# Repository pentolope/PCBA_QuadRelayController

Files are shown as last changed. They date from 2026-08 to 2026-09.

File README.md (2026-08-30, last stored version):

# Four-Channel Relay Controller

Four-channel relay controller run by a small MCU on 5 V logic, switching external loads through screw terminals with the switched side kept apart from logic.

This repository seeds the design of a four-channel relay controller operated by a small MCU, with 5 V logic power and each relay switching an external load through screw terminals. The brief fixes the functional block list — input protection, transistor/MOSFET relay drivers, flyback suppression, status indication, and a programming interface — and imposes one layout-level constraint: the switched side must be physically separated from the logic side, with conservative clearances appropriate to a voltage rating the design agent selects and documents. Beyond those items nothing is pinned down. No relay, MCU, driver device, terminal block, protection part, programming standard, board outline, or stackup is named. The switched-side voltage rating is explicitly delegated — it is one "you select and document" — while the switched-side current rating and whether the load is AC or DC are never mentioned at all, and so are open by silence. Most of the architecture therefore belongs to the design agent; the brief supplies the block list and the separation constraint, not the implementation.

> **This board has not been designed.** There is no schematic, no layout and no
> part selection here — only the brief, a reading of the brief, and the
> scaffolding a design run needs. That is the intended state of this repository,
> not a gap in it.

## What the brief fixes, and what it leaves open

The brief pins down 13 requirements and deliberately leaves
20 decisions to whoever designs the board. The `Source` column says
which is which: `brief` is quoted from [BRIEF.md](BRIEF.md), `metadata` comes
from the benchmark catalogue, and `open` means the brief does not fix it.

| Aspect | Value | Source |
|---|---|---|
| Channel count | Four relay channels | brief |
| Controller | A small MCU; no family, part, package or core named | brief |
| Logic supply | 5 V | brief |
| Load connection | Each relay switches an external load through screw terminals | brief |
| Relay driver stage | Transistor/MOSFET relay drivers required; device and topology unspecified | brief |
| Flyback suppression | Required; suppression method not specified | brief |
| Input protection | Required; protected nodes and scheme not specified | brief |
| Status indication and programming interface | Both required; indication form, programming standard and the physical form of the interface all unspecified | brief |
| High/low voltage partition | Switched side physically separated from logic side | brief |
| Switched-side voltage rating, current rating and clearance values | Not fixed by the brief; the design agent selects and documents the voltage rating and chooses conservative clearances appropriate to it. The current rating and whether the load is AC or DC are not mentioned at all and are equally the agent's to decide. | open |
| Relay selection (coil voltage, contact form and rating, mounting style) | Design agent's choice; the brief names no relay | open |
| Board outline, size, mounting and terminal pitch | Design agent's choice; the brief states no mechanical envelope | open |
| Likely layer count | 2 | metadata |
| Category / difficulty / brief detail | industrial-control; difficulty 2; detail 2 | metadata |

The full split, with the verbatim brief text substantiating every fixed
requirement, is in [board/requirements.md](board/requirements.md) and
machine-readably in [board/requirements.json](board/requirements.json).

**Missing details are design freedom, not permission to fabricate unstated user
requirements.** A choice the brief left open is recorded as a decision, with its
reasoning — never promoted into a requirement.

## Benchmark position

| | |
|---|---|
| Benchmark id | 3 of 32 |
| Category | industrial-control |
| Difficulty | 2 / 5 |
| Brief detail | 2 / 5 |
| Likely layer count | 2 |
| Primary stressors | high/low voltage partition, relay flyback, creepage/clearance, terminal placement |

At difficulty 2 and detail 2 in the industrial-control category, this board tests whether an agent can execute a conventionally-shaped circuit while getting the physical discipline right rather than the component novelty. The listed stressors — high/low voltage partition, relay flyback, creepage/clearance, terminal placement — are all layout and rating problems, and the brief deliberately withholds the switched-side voltage rating so the agent must select one, choose clearances that are conservative and appropriate to it, and live with the consequences in the floorplan. The real test is whether the separation barrier and the clearance numbers rest on a stated basis or are merely asserted.

This repository is one of thirty-two. The suite, the protocol and the results
live in [PCBA_AutoDesignAndTest_Bench](https://github.com/pentolope/PCBA_AutoDesignAndTest_Bench).

## Repository layout

| Path | Contents |
|---|---|
| `BRIEF.md` | the supplied brief — authoritative, preserved byte for byte, never edited |
| `board/requirements.md` | what the brief fixes, what it leaves open, and where decisions get recorded |
| `board/requirements.json` | the same split, machine-readable, each fixed requirement bound to brief text |
| `board/manifest.template.json` | the toolkit's minimum manifest, pre-filled for this board |
| `board/toolchain.json` | where this board's build finds KiCad and the router |
| `benchmark/metadata.json` | the supplied catalogue entry — category, difficulty, detail, stressors |
| `docs/architecture.md` | the decisions this board must make, as questions, unanswered |
| `docs/sources.md` | the classes of evidence the design will have to cite |
| `docs/status.md` | what exists, what does not, and what is deliberately absent |
| `candidates/` | disposable search output, ignored by Git |
| `.claude/skills/` | the accountability-review skill [CLAUDE.md](CLAUDE.md) requires before a push |
| `tooling/PCBA_AutoDesignAndTest` | the shared verification/routing/release toolkit, as a pinned submodule |

## Getting the repository

The toolkit is a submodule and carries KiCad Routing Tools as a submodule of its
own, so clone recursively:

```bash
git clone --recursive https://github.com/pentolope/PCBA_QuadRelayController.git
```

```bash
git submodule update --init --recursive
```

## Designing the board

Generic verification, routing and release logic is **not** written here. It is
consumed from `tooling/PCBA_AutoDesignAndTest`, which is board-agnostic by
construction and must stay that way; this repository owns the board and nothing
else. Start from
[the toolkit's onboarding guide](tooling/PCBA_AutoDesignAndTest/examples/onboarding.md),
and see [CLAUDE.md](CLAUDE.md) for the rules a design run works under.

```bash
python3 tooling/PCBA_AutoDesignAndTest/run.py preflight
```

## Brief integrity

`BRIEF.md` SHA-256 `7ed0a0647777bf47b7bdb843b795a63dda5a91aa048535087b107b13f95b585d`

Every quotation in `board/requirements.json` is bound to those exact bytes. If
the brief ever changes, the bindings are stale by construction — which is the
point of recording the digest.

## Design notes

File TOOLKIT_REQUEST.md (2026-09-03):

# Toolkit requests from 03_PCBA_QuadRelayController

What the toolkit would have to contain for this board to have been built with
less reinvention, for the gates it cannot turn on to become available, and for
the three claims it currently reports as UNKNOWN to become answerable.

Everything here is asked for board-agnostically: no request names this board,
its parts or its net names, and each is written as a capability any board
would use. Where a request is grounded in something that happened here, the
specific number is given so the request can be judged rather than taken on
trust.

Board state at the time of writing: 26 gates PASS, 10 NOT_APPLICABLE, 0 FAIL;
78 claims, of which 75 PASS and 3 are UNKNOWN.

---

## 1. A machine-readable manifest schema

**The single largest cost of this board.** Every manifest declaration made in
this session was reverse-engineered by reading gate source and toolkit tests:
`simulation.models`, `simulation.extracted_models`, `timing.interfaces`,
`release_generation.cpl_orientation`, `release_generation.fab_format`,
`via_mask`, `reports.source_closure`. `schemas/` contains only KiCad's own DRC
and ERC schemas, and no document lists manifest keys.

Two concrete failures this caused:

- `timing.interfaces.<name>` needs its paths wrapped in a `routes` object. I
  declared `template`/`bindings` at the interface level, which is well-formed
  JSON, produces no schema error, and fails four gates with
  `PathError: declares no routes`. One full validation cycle to discover a
  key name.
- `release_generation.fab_format` is not mentioned anywhere outside
  `build.py`. Without it the orientation registry silently does nothing (see
  §3 below).

**Request:** a JSON Schema for the manifest, published in `schemas/`, and a
`run.py validate` preflight that checks the manifest against it before any
gate runs. A declaration that names a key the toolkit does not implement
should be refused rather than ignored — the same fail-closed rule the model
registry already applies to unknown model keys.

Secondary, and cheap: `run.py gates --requires <key>` or a generated table of
gate → required manifest keys → link to the schema node. `run.py gates`
already prints the `requires` tuples; what is missing is the shape behind each
key.

---

## 2. Thermal, at all

Section 24 of the architecture asks for thermal as a first-class verification
domain. The toolkit has no thermal gate, no dissipation model, no ambient
declaration and no junction-temperature discipline. I built all of it in the
board (`design/thermal.py`), and every board will build it differently.

Three pieces, in order of value:

### 2a. A declared maximum ambient, and derating from it

The manifest should carry the board's maximum ambient as a first-class
constraint, and there should be a gate that refuses a package rating used at
an ambient the rating was not quoted at.

This caught a real defect here. A driver was judged against its datasheet's
0.9 W figure; that figure is quoted against the part's **ten-second**
junction-to-ambient resistance, so it is a transient rating and the driver is
on continuously. The steady-state limit at the declared ambient is 0.88 W,
derived from the same datasheet's junction limit and steady-state resistance.
The rule generalises: *a power limit applied to a continuously-conducting part
must come from a steady-state thermal resistance, and must be re-derived at
the board's declared ambient rather than read at the datasheet's.*

### 2b. A gate that refuses an unsupported junction-temperature claim

Section 24 already states the rule — a board should not claim a junction
temperature from a generic θJA when the boundary conditions do not match its
validity — and nothing enforces it. The datasheet figures used here are
measured on one square inch of two-ounce copper in still air; this board is
two-layer one-ounce.

**Request:** let a thermal parameter record carry its measurement boundary
conditions, and let a gate compare them against the board's actual stackup and
copper. A mismatch should force the claim to be reported as conditional rather
than as a junction temperature. The pattern this board fell back to — report
the *factor* by which the board's thermal path could be worse than the
datasheet's test board before the limit is reached — is a reasonable default
for the conditional form.

### 2c. A geometry-derived thermal model

**This one closes two of this board's three UNKNOWN claims**, so it is the
highest-value item in this document for verifying reliability:

- `board_temperature_rise_above_ambient` — UNKNOWN. Needs the board's thermal
  resistance to ambient.
- `switched_copper_temperature_rise` — UNKNOWN. Needs a conductor-sizing
  basis. IPC-2152 is copyrighted and cannot be frozen into a repository, but
  a first-principles model — I²R into a copper-and-laminate spreading model
  with a stated convection assumption — is derivable, freezable, and would
  produce a bounded claim where there is currently none.

The toolkit already has everything this needs as inputs: `pcbqa.extract`
traverses real copper, the fabricator catalog supplies finished copper
thickness and board thickness as approved-evidence parameters, and
`pcbqa.claim` can express the result as a bound with its assumptions attached.
What is missing is the solver between them. Even a crude one — 2-D copper
spreading, one convection coefficient declared as an assumption, no radiation
— converts two "we cannot say" claims into "at most N degrees, under these
stated assumptions", which is the difference the evidence model exists to
make.

A third UNKNOWN (parts whose datasheets state no operating temperature range)
is not something the toolkit can fix.

---

## 3. `release_generation.fab_format` silently skips orientation

A genuine trap, and the only one in this session that would have shipped a
wrong board rather than merely costing time.

`Build.orient_cpl` is only reachable from `Build.format_for_fab`, which
returns immediately when the manifest declares no `fab_format`. A board can
therefore declare a complete, reviewed, evidence-backed `cpl_orientation`
registry, and the build will apply none of it. The placement file ships with
raw layout angles.

`CPL.ORIENTATION` does catch it afterwards, which is why this is a trap and
not a hole. But the build reports success, logs nothing, and the failure
surfaces at a gate that names a different cause.

**Request:** a build that has `release_generation.cpl_orientation` and no
`fab_format.cpl` should refuse with a message naming the missing key. More
generally: any declared capability whose application step is unreachable
should be a build blocker, not a silent skip.

---

## 4. A reference implementation for library-zero orientation

`CPL.ORIENTATION` requires the board to supply `tools/jlc_orientation.py` with
`HERE`/`FIXTURES`/`BOARD` globals and a `derive()` that returns
`{part number: {best_offset_deg, best_worst_deg, margin_deg, decisive,
evidence_sha256, evidence_problems}}`. Nothing in the toolkit, its tests or
its documentation says what that script should compute, and no example exists
anywhere in the bench.

Keeping the script inside the project is right — that is what puts it in the
source closure and lets `PROV.SOURCE_CLOSURE` check the content that actually
ran. The *algorithm*, however, is board-agnostic, and getting it wrong is
silent: I had to reason through the y-up/y-down handedness of two libraries,
and through the fact that pairing pads by position cannot distinguish a
polarised two-pad part from the same part reversed. On this board that
distinction was not academic — the LED needs a 180° correction and the diode
beside it needs none, and position matching would have called them the same.

**Request:** ship a reference derivation as a vendorable file (`examples/` or
`profiles/jlcpcb/`) that a board copies in, plus a schema for the frozen
evidence record. Two properties the reference should carry, because both are
easy to get wrong and neither is checkable after the fact:

- pairing by pad number where the two libraries agree on numbering, falling
  back to positional matching only where they do not, **and recording which
  was used** — positional matching decides only what the geometry decides;
- scoring from the raw response body rather than from any normalised extract,
  so that editing the extract produces a visible mismatch rather than a
  different answer.

A `Registry` review status of `reviewed` currently cannot distinguish "a human
compared the part against the library" from "a script derived it from frozen
evidence and re-derives it every release". The second is what an autonomous
agent can honestly produce, and arguably the stronger of the two, but the
field cannot say so. A `review_basis` field with a controlled vocabulary would
let the distinction be recorded rather than argued in a commit message.

---

## 5. Router and placer friction that every board will hit

### 5a. The router reads clearance from the project, not from `--clearance`

Requesting 0.15 mm produced 0.114 mm of actual clearance. The figure the
router honours comes from the project's Default netclass, not from the
`--clearance` argument. The workaround — write a throwaway project with the
Default clearance raised to a margin value, route against it, then restore the
authoritative project and judge against that — is about forty lines that every
board will now carry.

**Request:** either honour `--clearance`, or state in the routing record what
clearance was actually applied so a board can check it rather than measure it.
The margin-project dance belongs in the toolkit if it belongs anywhere.

### 5b. Netclass patterns in `.kicad_pro` are not honoured by `kicad-cli pcb drc`

Every net resolves to Default. I confirmed this by probing, then moved the
board's two insulation clearances into `.kicad_dru` as net-name wildcard rules
and deleted the netclasses, which were judging nothing.

This is KiCad behaviour, not toolkit behaviour, but it is exactly the kind of
silent no-op a validator should refuse to let a board rely on.

**Request:** a check that fails when a project declares netclass membership
patterns and the DRC path in use ignores them — i.e. when a board's design
rules are less strict in practice than the manifest says they are.

### 5c. The placer refuses a board with copper

Correct behaviour — moving a footprint does not move copper — but it means a
board must be able to generate a copper-free variant of itself for placement,
and then regenerate everything conductive from the accepted poses. That is a
workflow every board needs and each will invent. Worth a documented pattern,
or a `run.py place` that manages the seed/optimise/adopt cycle the way
`run.py build` manages the export cycle.

---

## 6. A fast board-integrity preflight

Twice in this session the routed board in the tree was replaced by an
unrouted regeneration — 444 track segments down to 66 — with no command of
mine writing it. On the second occasion a stray `.kicad_prl` belonging to a
*different* board appeared in this directory at the same second, and another
session was demonstrably working in the bench at the time. `ROUTE.PROVENANCE`
caught it, but only at the end of a full validation run, and the first
symptom was an unrelated-looking extraction error.

I added a board-local unit test that hashes the board against
`generated/routing.json`'s `adopted_sha256`. It costs a hash and it is
board-agnostic.

**Request:** `run.py check-board <manifest>` — a sub-second preflight that
verifies the tree's board is the accepted routing candidate and that the
source closure digests still hold, without running DRC, extraction or
simulation. Useful as a pre-commit hook and as the first thing a long
autonomous run does after any external tool touches the tree.

Related, and worth considering separately: the toolkit has no notion of two
processes working in one bench. A lock file keyed on the project root, or a
refusal when a KiCad artifact naming a different project appears beside the
board, would have turned a confusing hour into an immediate error.

---

## 7. Statement kinds and verification methods belong on the requirement

`claim.requirement()` accepts exactly `{name, source, assertion}` and
`_validate_requirement` refuses anything else. Sections 4 and 26 of the
architecture ask for more than that: a requirement should say whether it is a
user requirement, a derived requirement, an assumption or a design decision,
and it should name the verification methods that establish it.

With no field to carry either, this board built a side register
(`constraints/requirements.json`) and encoded the kind into the source string
as `"<kind>:<origin>"`. It works, it is checked in both directions, and it is
a board-local convention that the next board will reinvent differently.

**Request:** first-class `kind` and `verification_methods` fields on a
requirement record, with the §4 and §26 vocabularies as the accepted values,
and validation rules per kind — a derived requirement states what it was
derived from, a design decision states its alternatives, an assumption states
what would invalidate it.

**Request, related:** a gate that joins the claim set to a requirement
register in both directions. A claim judged against an unregistered
requirement and a registered requirement nothing is judged against are both
defects, and neither is currently detectable. This board implements the join
itself; the check is entirely generic.

---

## 8. Evidence documents are cited but never verified

`evidence/index.json` records each datasheet's sha256. The index is in the
source closure; **the documents are not**, and no gate compares a document on
disk against the digest the index claims for it. A datasheet can be replaced
with a different revision and nothing objects, while every claim citing it
continues to look fresh.

The orientation work shows the shape of the fix, because it already does this
properly: the raw library response and its extract are both committed, both
are in the closure, and the extract is re-derived from the body on every read.

**Request:** a `PROV.EVIDENCE_INTEGRITY` gate — every document an evidence
index names exists, matches its recorded digest, and is inside the source
closure; and every document id cited by a parameter record or a claim resolves
to an index entry. The second half of that is what this board implements in
`design/requirements.py::check_origins`, and it is generic.

---

## 9. Two missing simulation primitives

Both were hit deriving the coil turn-off transient, and both are generic to
any board with an inductive load — relays, solenoids, motors, buck converters.

### 9a. No current source

`_ELEMENT_KEYS` offers resistor, capacitor, inductor, `vsource_dc`,
`vsource_pulse` and `model_instance`. There is no current source, so forcing a
known current requires a Thevenin stand-in: a large voltage source and a
series resistance sized against a voltage the measured node provably cannot
reach, so the delivered current is never short. That works and is defensible,
but it is a workaround for a missing primitive and it puts an arithmetic
argument in the board where an element kind would do.

### 9b. No initial condition on an inductor

An inductor's element record is `{kind, name, nodes, value}` with no initial
current, and no analysis kind emits `.ic`. This is why the turn-off scenario
here establishes only the clamp *level* at the instant of switching, and says
nothing about the decay time or the energy the flyback device absorbs. With an
initial condition, the same frozen models would answer both.

**Request:** an `isource_dc` element kind, and an optional `ic` on the
inductor with `.ic` emitted by the ngspice backend.

---

## 10. Inductance extraction

`claim.PHENOMENA` includes `loop_inductance`, and nothing in the toolkit
produces it. `pcbqa.extract` traverses real copper and returns DC resistance
only.

The consequence here: this board declares a flyback turn-off **loop area**
target and checks the geometry against it. Area is a proxy. The quantity that
actually stresses the driver is the loop's inductance, through L·di/dt, and it
is the quantity the claim would rather be about. Because no extractor produces
it, the requirement is registered as a design decision — a self-imposed
numeric target — rather than as a derived requirement with a physical basis.

**Request:** a geometry-derived loop-inductance extraction over a declared
current loop, at the same evidence class the DC-resistance extraction already
carries (`geometry-derived`, board digest embedded, omissions stated). Any
board with a switching element and a commutation loop wants this, and it is
the same copper traversal that already exists.

---

## 11. Fabricator catalog: the via-to-mask process limit

`VIA.MASK_CLEARANCE_PROCESS` and `VIA.NATIVE_GERBER_AGREEMENT` both require
`via_mask.process.limit_mm`. The approved JLCPCB catalog carries via hole and
diameter minima but no via-annulus-to-solder-mask-opening figure — I checked
the normalised catalog and the raw evidence pages. Declaring the number from
memory would be inventing a process limit, so this board declares only its own
0.15 mm design target and two gates stay NOT_APPLICABLE.

**Request:** capture the fabricator's mask-registration and
via-to-mask-opening limits into the approved catalog. One number turns on two
gates for every board.

---

## Not requested

Recorded so the list above is not read as exhaustive of what was noticed.

- `ROUTE.ANGLE_STYLE` staying NOT_APPLICABLE is this board's decision, not a
  toolkit gap. The routing is 252-of-270 corners on multiples of 45°; the
  census is recorded and no angle style is declared, because nothing in the
  brief, the insulation standard or the fabricator's capabilities asks for
  one.
- `TIMING.INTERCONNECT_DELAY` and `TIMING.INTERCONNECT_SKEW` reporting
  measurements and asserting nothing, where a board declares no limit, is
  correct. A relay command has no picosecond budget and inventing one would be
  inventing a requirement.
- `TIMING.SETUP_HOLD`, `FAB.LAYER_IDENTITY` and `PROV.FIXTURE_INTEGRITY` are
  genuinely not this board's: no synchronous interface at speed, no
  net-named inner copper, no frozen fixture.
- The model registry's `CONDITIONS` tuple carrying only `temperature_c` was
  sufficient here, and its own comment already says what it is waiting for.

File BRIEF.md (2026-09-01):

# PCBA_QuadRelayController — Four-Channel Relay Controller
## Design brief

Design a four-channel relay controller operated by a small MCU. Logic power is 5 V; each relay switches an external load through screw terminals. Include input protection, transistor/MOSFET relay drivers, flyback suppression, status indication, and a programming interface. Keep the switched side physically separated from the logic side and choose conservative clearances appropriate to the voltage rating you select and document.

## Functional requirements

- The four channels shall be independently commandable; changing one shall not disturb the others.
- All coils shall be de-energised at power-on, in MCU reset, while a programmer holds reset, and on loss of logic power.
- Status indication shall show each channel's commanded state, driven from the logic side only.

## Power and rails

- The board shall run from an external 5 V logic input; any further rail shall be derived on-board or given its own documented input.
- With all coils energising at once at worst-case supply tolerance, the logic rail shall stay inside the MCU's operating range and above brown-out.
- The 5 V input shall tolerate reverse polarity, and every logic-side conductor entering the board shall withstand ESD and hot connection.

## Relay drive and flyback suppression

- Each coil shall be driven by a transistor or MOSFET stage fully on at the drive level the chosen MCU guarantees, with dissipation and total pin current within ratings when all four channels are on at maximum ambient.
- Each driver input shall be resistively held de-energised whenever the MCU pin is high-impedance or unprogrammed.
- Each coil shall have its own flyback device in a small turn-off loop, rated for the coil current and clamping below the driver's breakdown voltage.

## Connectors and programming interface

- Switched circuits shall reach the outside world only through the screw terminals, which shall be rated at or above the documented switched voltage and current.
- Terminals shall take load wiring away from the logic side and be identified on the silkscreen by channel and contact function.
- The programming interface shall program the chosen MCU in circuit on an assembled board, with no part removed, from the logic side of the boundary.

## Separation, clearance and markings

- The switched/logic boundary shall be continuous on every layer; nothing conductive shall cross it but the relay contact pins and their terminals.
- Clearance and creepage across the boundary, and between switched-side conductors, shall meet the figure derived from the documented rating; solder mask shall not count toward it.
- That rating, the standard used to derive the clearance and the resulting minimum dimension shall be documented, and the per-channel maximum voltage and current marked on the board.

## Test and bring-up

- Each channel shall be exercisable individually with no load fitted, with contact transfer verifiable at the terminals.
- Logic-side test access shall expose the 5 V rail, ground, the coil supply, and each driver input and coil node.

## Open choices

- MCU: any part with enough I/O for the drivers, the indication and the programming interface, a defined reset state, and adequate guaranteed drive.
- Relay coil voltage and contact configuration, whether coils share the 5 V logic rail or take a separate supply, and the switched-side rating the clearances depend on.
- Where channel commands originate — firmware, local inputs, or a host interface — and whether that interface is isolated.

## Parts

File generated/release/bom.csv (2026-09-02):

Quantity | Designator | Comment | Footprint | LCSC Part #
3 | C1,C2,C3 | 10uF | Capacitor_SMD:C_0805_2012Metric | C15850
3 | C4,C5,C6 | 100nF | Capacitor_SMD:C_0603_1608Metric | C14663
4 | D1,D2,D3,D4 | 1N4148W | Diode_SMD:D_SOD-123 | C81598
5 | D5,D6,D7,D8,D9 | KT-0603R | LED_SMD:LED_0603_1608Metric | C2286
7 | D10,D11,D12,D13,D14,D15,D16 | TPD1E10B06DPYR | QuadRelayController:TI_X1SON-2_1.0x0.6mm_P0.65mm | C48260
1 | J1 | KF128-5.08-2P-AA | QuadRelayController:TerminalBlock_KF128-5.08_1x02_P5.08mm | C474952
4 | J2,J3,J4,J5 | HB9500M-9.5-03P-13-00A | TerminalBlock_Ningbo-Kagnex:TerminalBlock_Ningbo-Kagnex_HB9500M_1x03_P9.5mm | C162697
1 | J6 | KH-2.54PH180-1X5P-L11.5 | Connector_PinHeader_2.54mm:PinHeader_1x05_P2.54mm_Vertical | C2932699
1 | J7 | KH-2.54PH180-1X4P-L11.5 | Connector_PinHeader_2.54mm:PinHeader_1x04_P2.54mm_Vertical | C2905435
4 | K1,K2,K3,K4 | G2RL-1-E DC5 | Relay_THT:Relay_SPDT_Omron_G2RL-1-E | C1524515
4 | Q1,Q2,Q3,Q4 | AO3400A | Package_TO_SOT_SMD:SOT-23 | C20917
1 | Q5 | AO3401A | Package_TO_SOT_SMD:SOT-23 | C15127
4 | R1,R2,R3,R4 | 100R | Resistor_SMD:R_0603_1608Metric | C22775
4 | R5,R6,R7,R8 | 2.2k | Resistor_SMD:R_0603_1608Metric | C4190
5 | R9,R10,R11,R12,R13 | 1.5k | Resistor_SMD:R_0603_1608Metric | C22843
1 | R14 | 100k | Resistor_SMD:R_0603_1608Metric | C25803
1 | R15 | 10k | Resistor_SMD:R_0603_1608Metric | C25804
1 | R16 | 4R7 | Resistor_SMD:R_0603_1608Metric | C23164
1 | U1 | PY32F003F18P6TU | Package_SO:TSSOP-20_4.4x6.5mm_P0.65mm | C5379864

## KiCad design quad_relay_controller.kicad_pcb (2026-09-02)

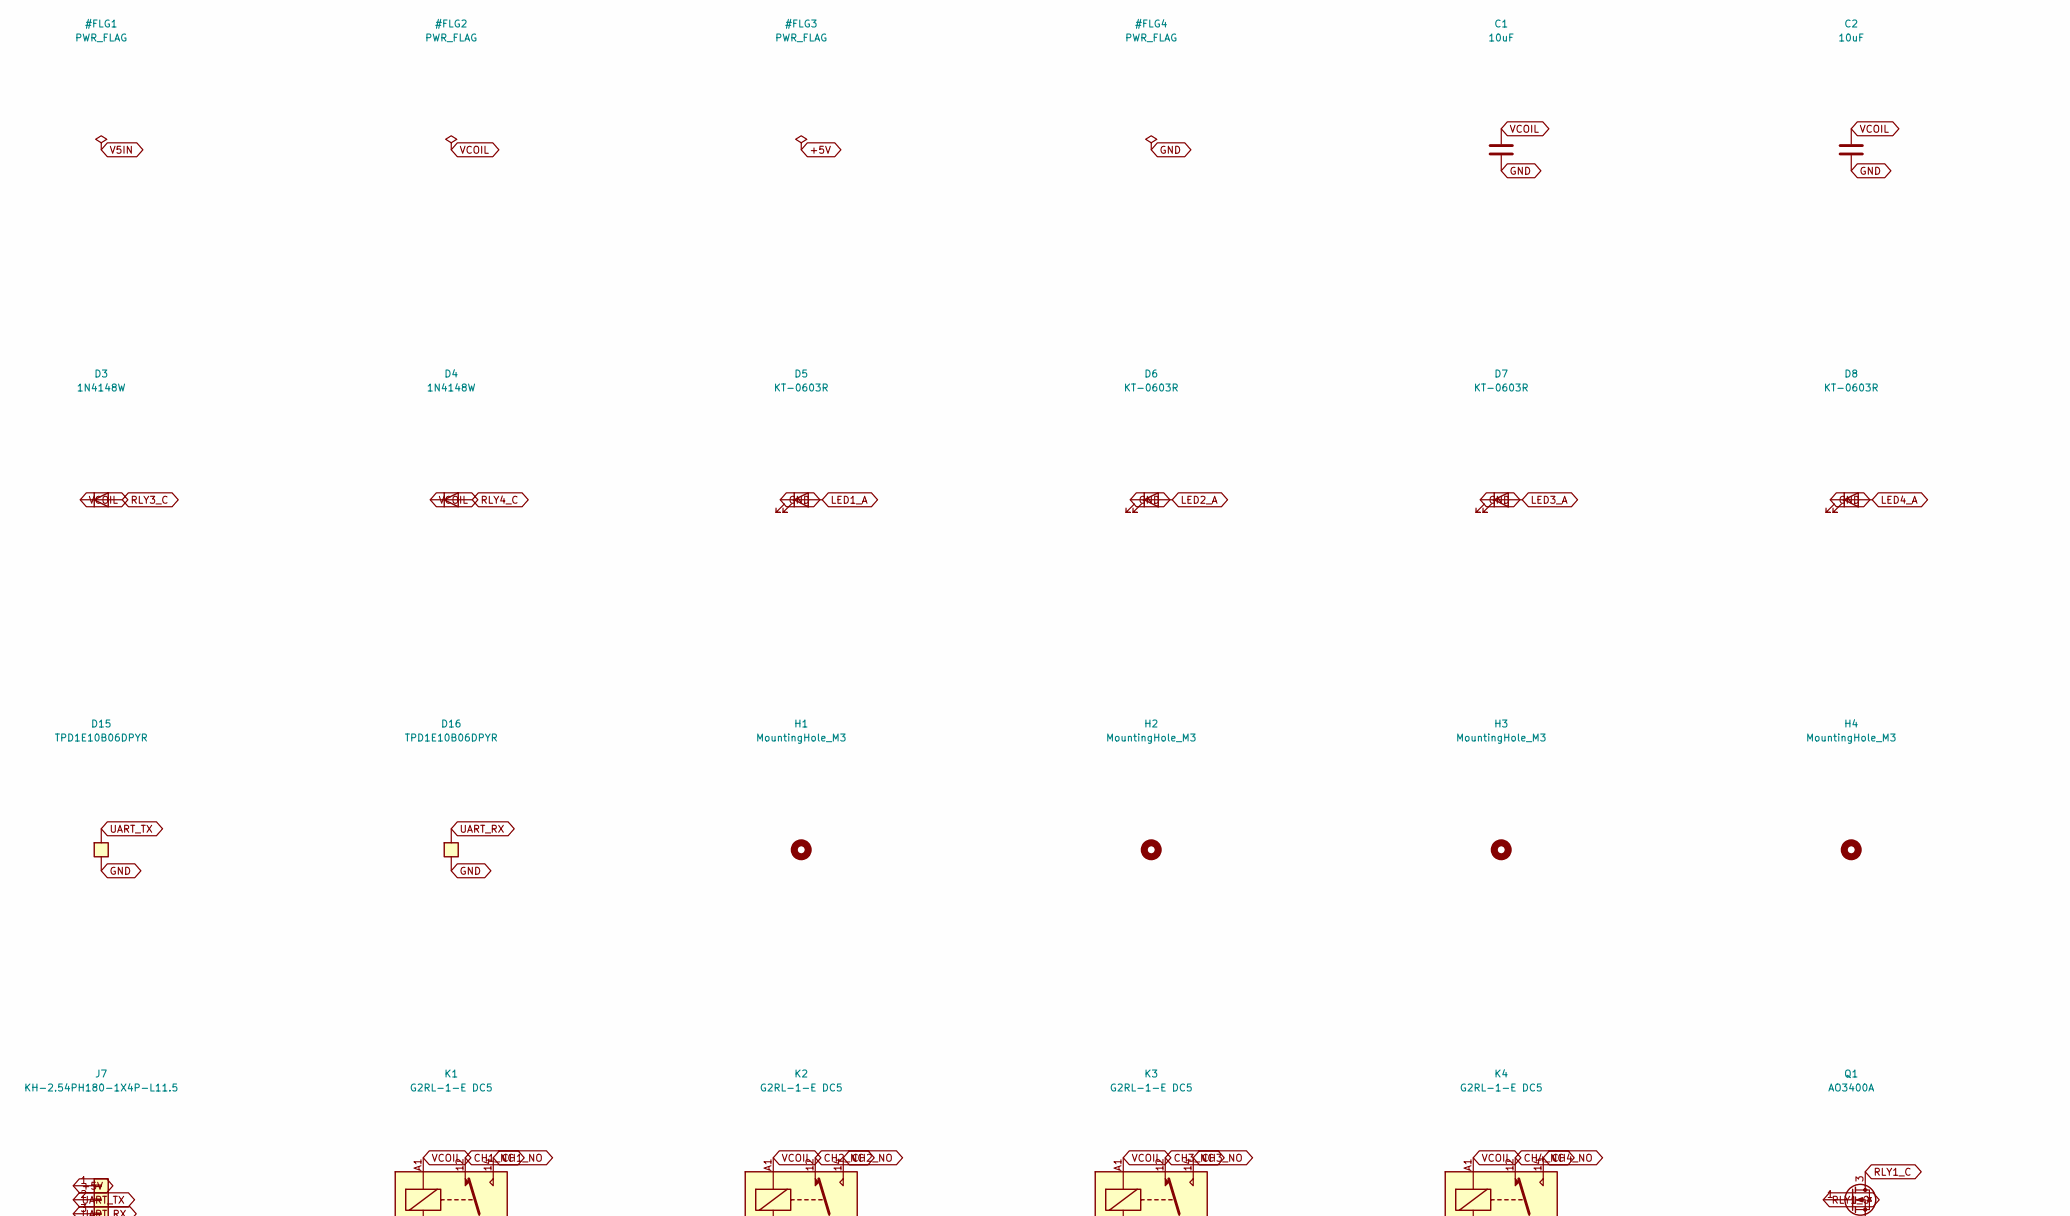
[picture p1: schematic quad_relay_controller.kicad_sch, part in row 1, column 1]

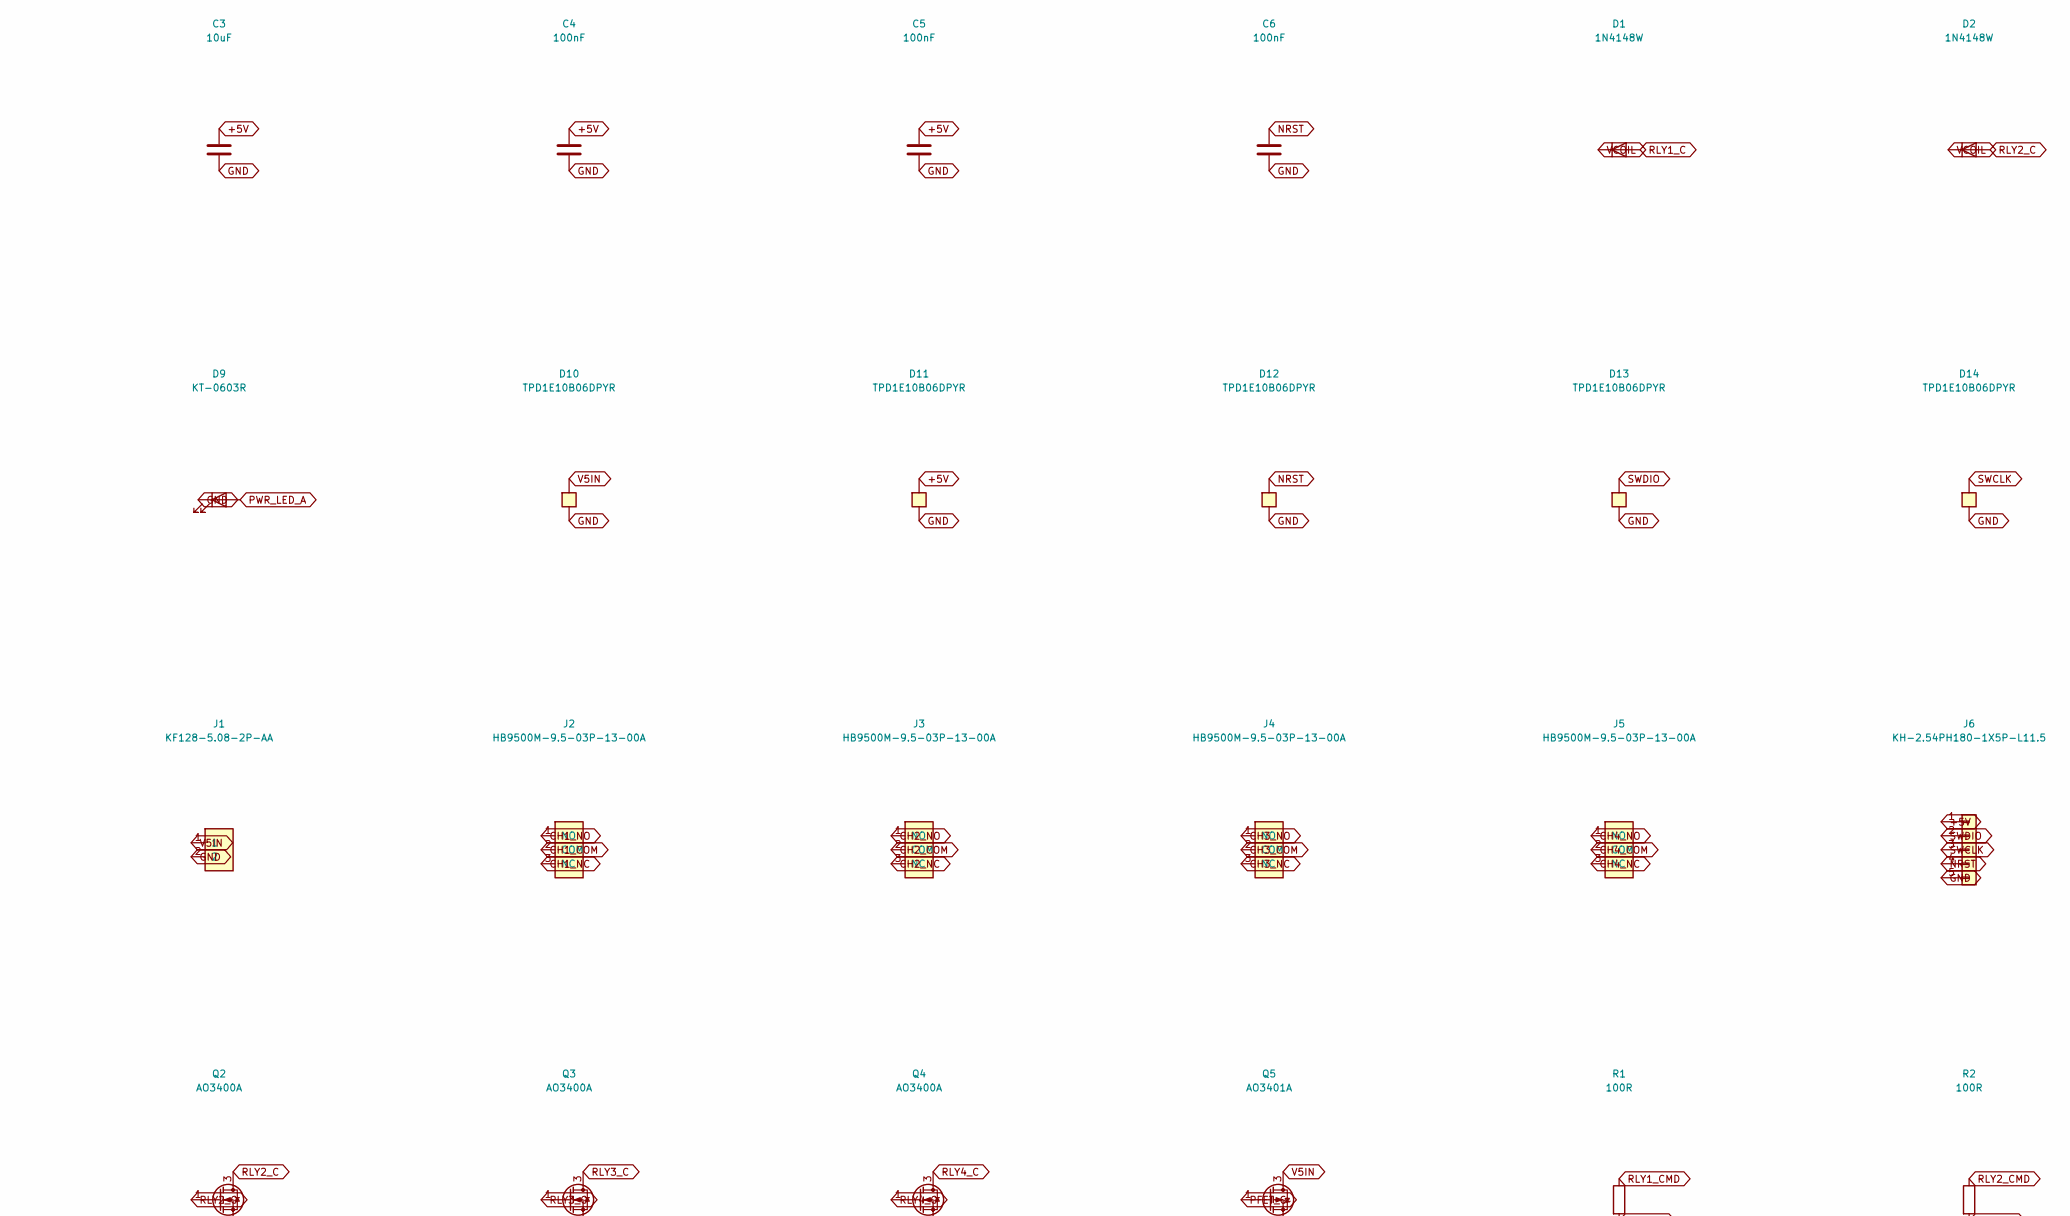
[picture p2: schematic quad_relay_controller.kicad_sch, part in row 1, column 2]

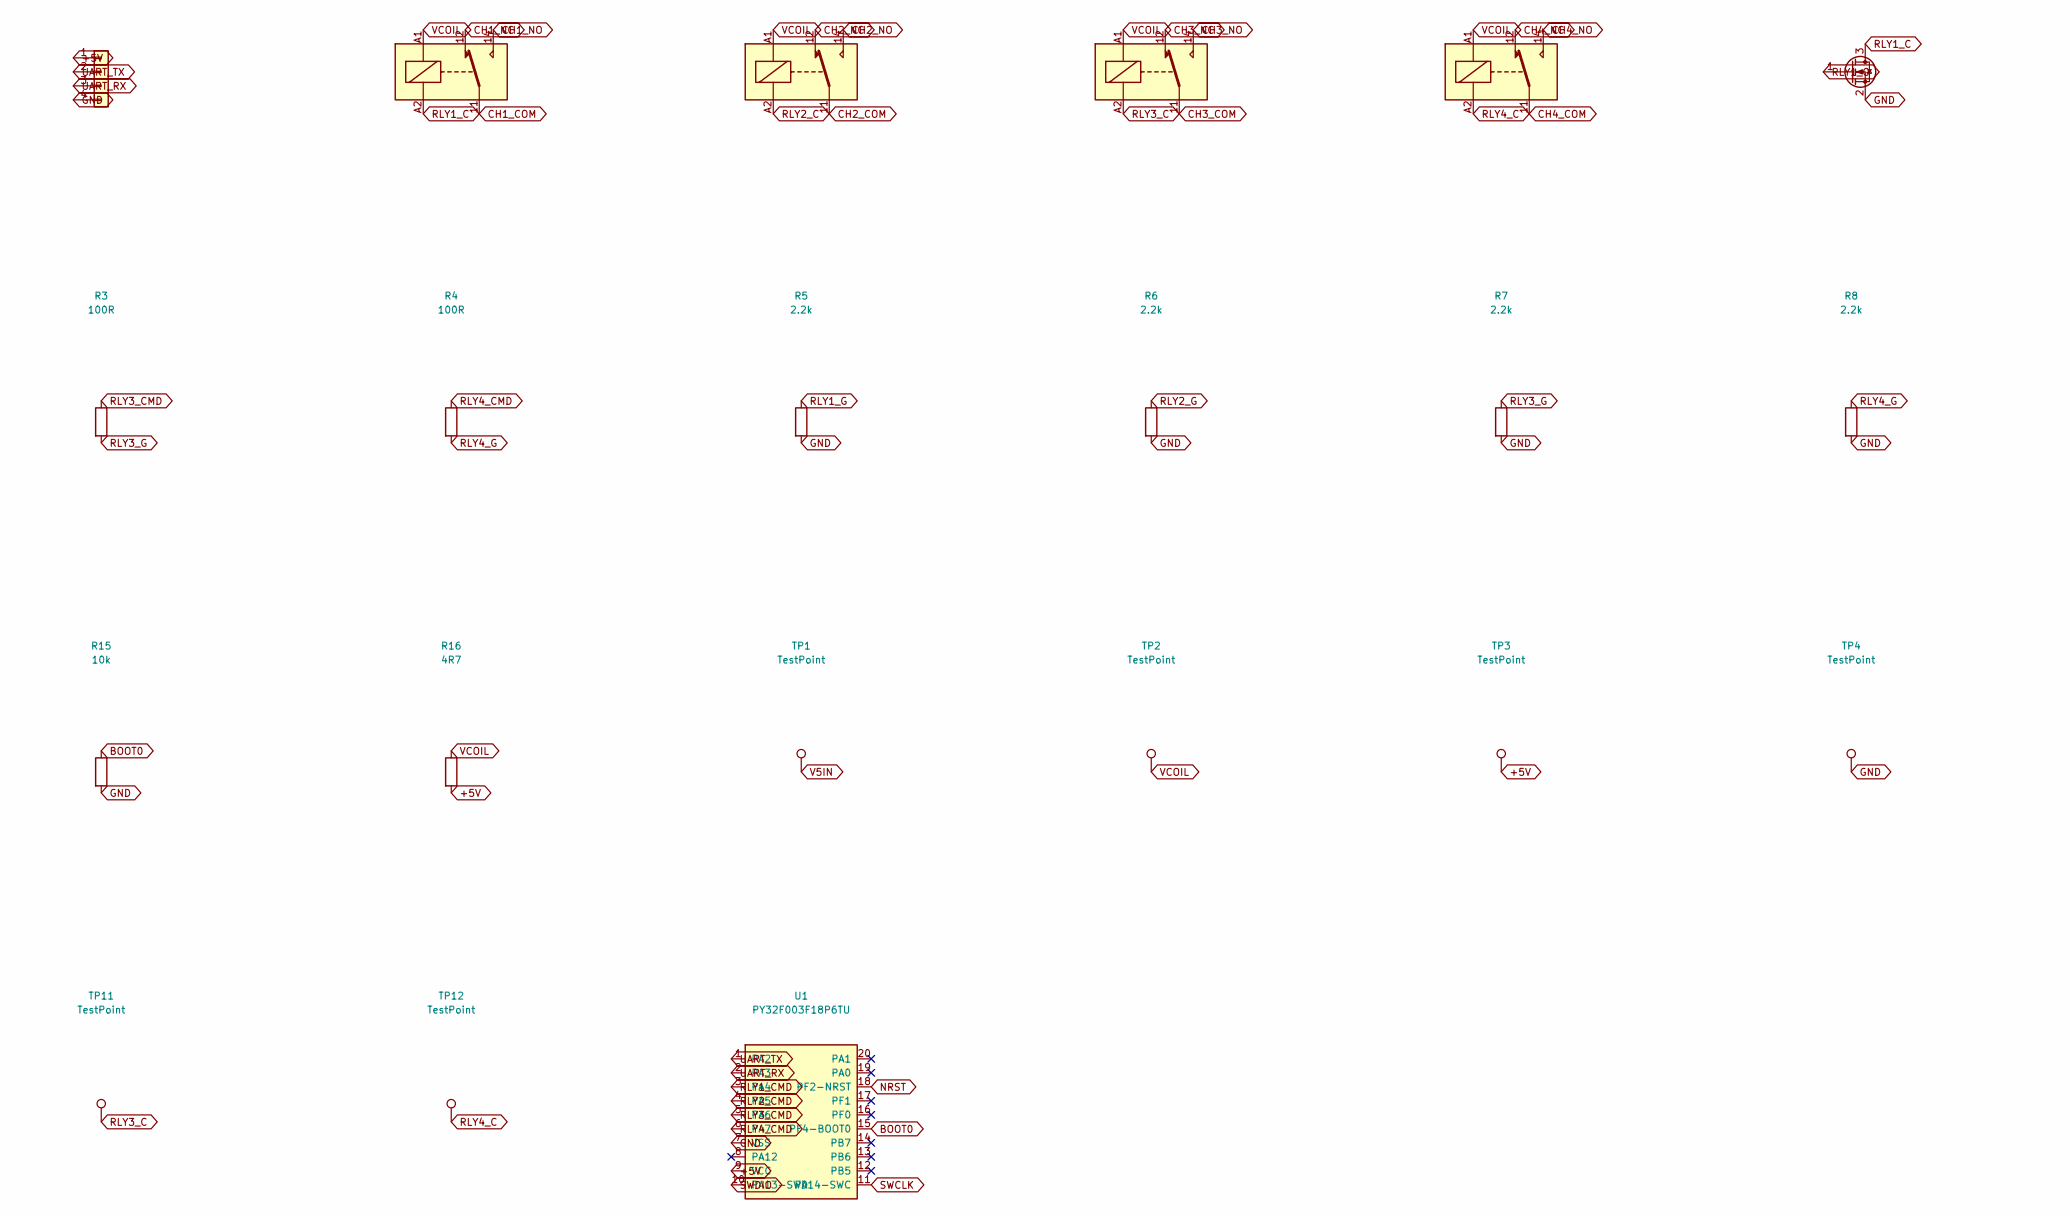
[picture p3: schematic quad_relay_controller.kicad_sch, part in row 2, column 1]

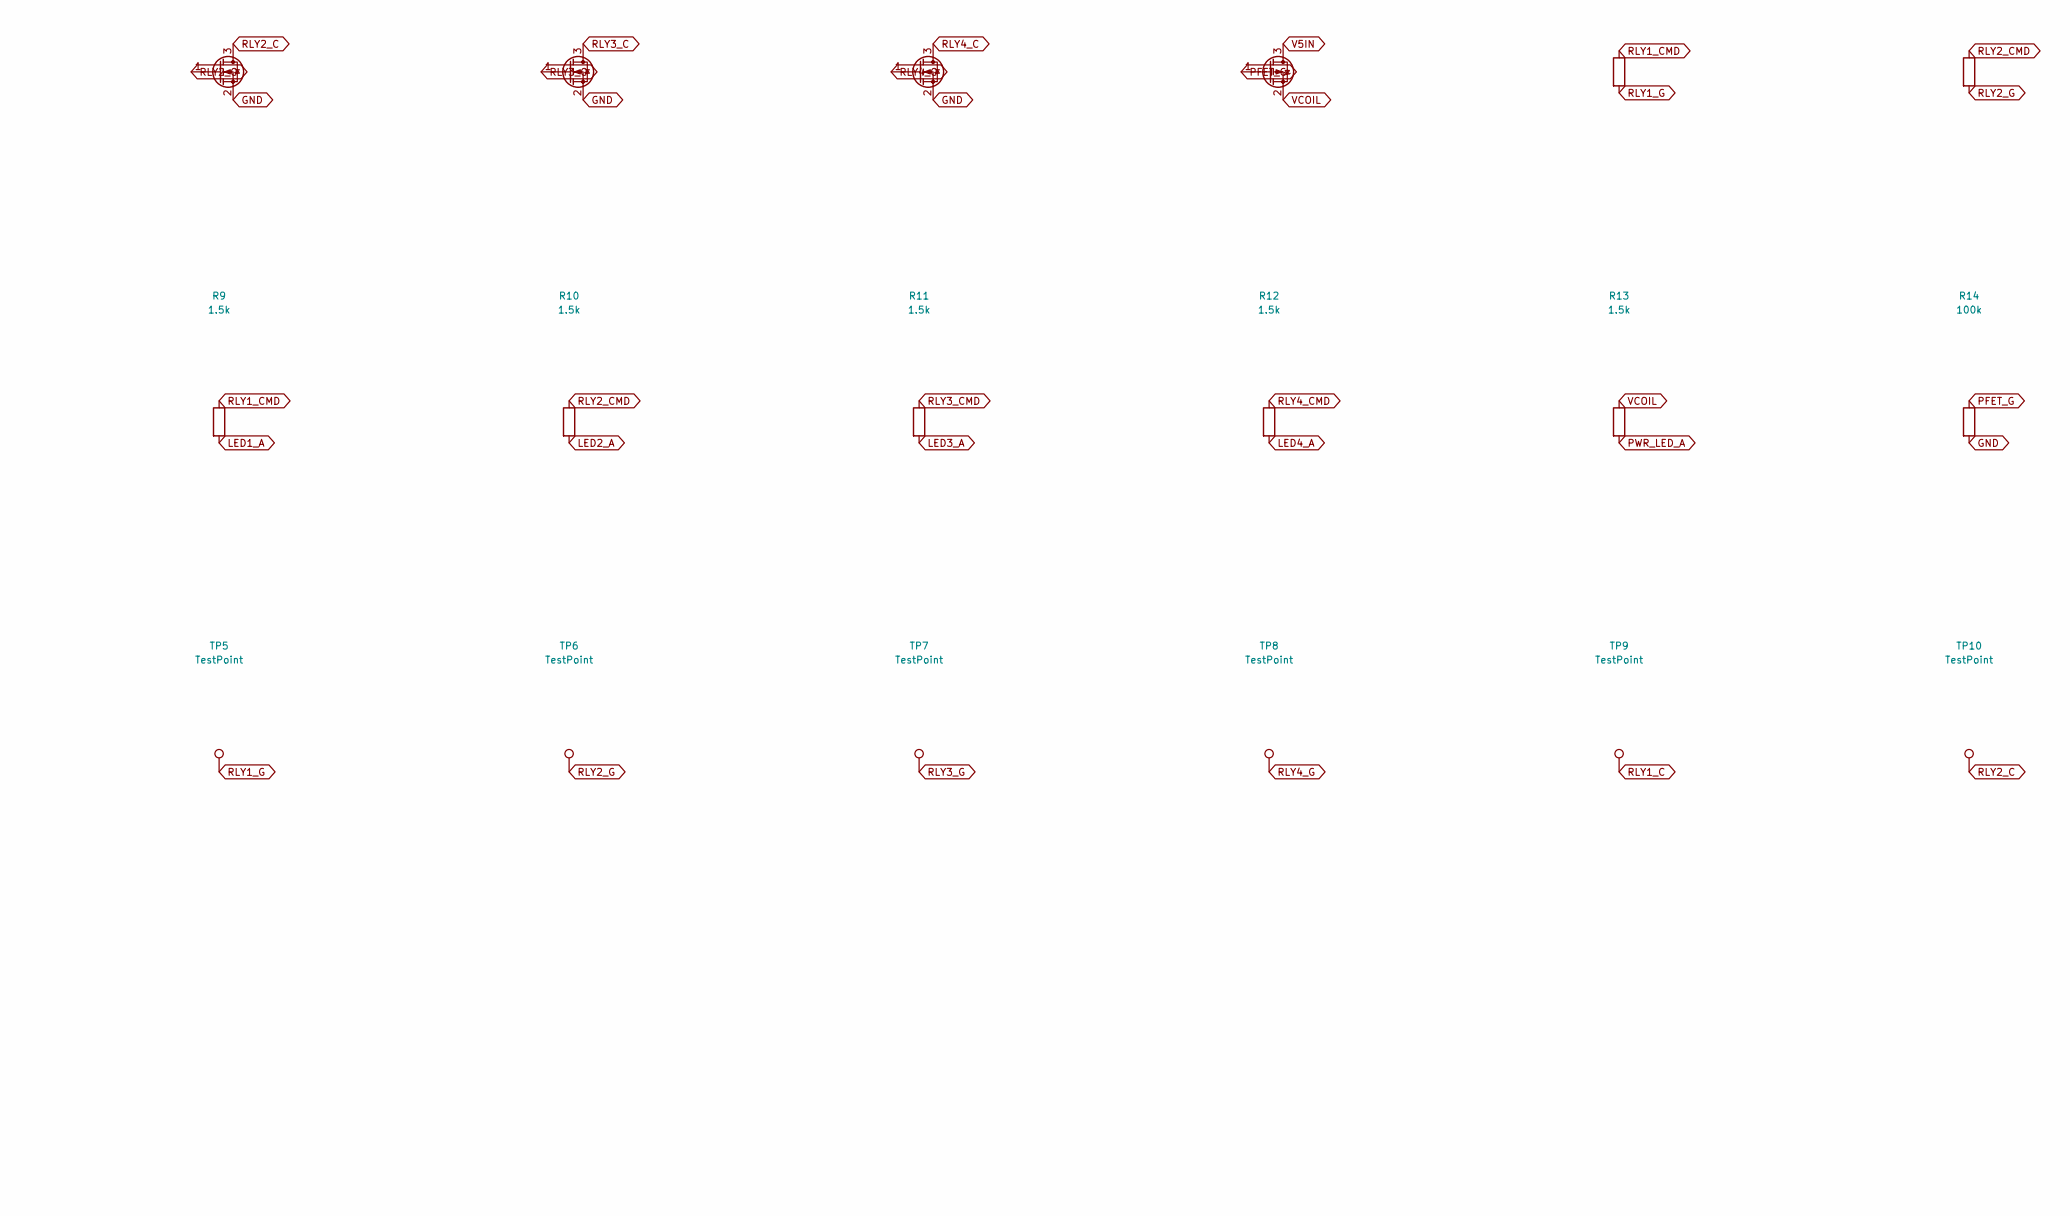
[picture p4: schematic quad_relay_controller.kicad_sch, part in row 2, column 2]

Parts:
C1, C2, C3: 10uF; C_0805_2012Metric; MPN CL21A106KAYNNNE; LCSC C15850
C4, C5, C6: 100nF; C_0603_1608Metric; MPN CC0603KRX7R9BB104; LCSC C14663
D1, D2, D3, D4: 1N4148W; D_SOD-123; MPN 1N4148W; LCSC C81598
D5, D6, D7, D8, D9: KT-0603R; LED_0603_1608Metric; MPN KT-0603R; LCSC C2286
D10, D11, D12, D13, D14, D15, D16: TPD1E10B06DPYR; TI_X1SON-2_1.0x0.6mm_P0.65mm; MPN TPD1E10B06DPYR; LCSC C48260
H1, H2, H3, H4: MountingHole_M3; MountingHole_3.2mm_M3
J1: KF128-5.08-2P-AA; TerminalBlock_KF128-5.08_1x02_P5.08mm; MPN KF128-5.08-2P-AA; LCSC C474952
J2, J3, J4, J5: HB9500M-9.5-03P-13-00A; TerminalBlock_Ningbo-Kagnex_HB9500M_1x03_P9.5mm; MPN HB9500M-9.5-03P-13-00A; LCSC C162697
J6: KH-2.54PH180-1X5P-L11.5; PinHeader_1x05_P2.54mm_Vertical; MPN KH-2.54PH180-1X5P-L11.5; LCSC C2932699
J7: KH-2.54PH180-1X4P-L11.5; PinHeader_1x04_P2.54mm_Vertical; MPN KH-2.54PH180-1X4P-L11.5; LCSC C2905435
K1, K2, K3, K4: G2RL-1-E DC5; Relay_SPDT_Omron_G2RL-1-E; MPN G2RL-1-E DC5; LCSC C1524515
Q1, Q2, Q3, Q4: AO3400A; SOT-23; MPN AO3400A; LCSC C20917
Q5: AO3401A; SOT-23; MPN AO3401A; LCSC C15127
R1, R2, R3, R4: 100R; R_0603_1608Metric; MPN 0603WAF1000T5E; LCSC C22775
R5, R6, R7, R8: 2.2k; R_0603_1608Metric; MPN 0603WAF2201T5E; LCSC C4190
R9, R10, R11, R12, R13: 1.5k; R_0603_1608Metric; MPN 0603WAF1501T5E; LCSC C22843
R14: 100k; R_0603_1608Metric; MPN 0603WAF1003T5E; LCSC C25803
R15: 10k; R_0603_1608Metric; MPN 0603WAF1002T5E; LCSC C25804
R16: 4R7; R_0603_1608Metric; MPN 0603WAF470KT5E; LCSC C23164
TP1, TP2, TP3, TP4, TP5, TP6, TP7, TP8, TP9, TP10, TP11, TP12: TestPoint; TestPoint_Pad_D1.0mm
U1: PY32F003F18P6TU; TSSOP-20_4.4x6.5mm_P0.65mm; MPN PY32F003F18P6TU; LCSC C5379864

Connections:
+5V: C3.1, C4.1, C5.1, D11.2 (A2), J6.1, J7.1, R16.2, TP3.1, U1.9 (VCC)
BOOT0: R15.1, U1.15 (PF4-BOOT0)
CH1_COM: J2.2 (COM), K1.11
CH1_NC: J2.3 (NC), K1.12
CH1_NO: J2.1 (NO), K1.14
CH2_COM: J3.2 (COM), K2.11
CH2_NC: J3.3 (NC), K2.12
CH2_NO: J3.1 (NO), K2.14
CH3_COM: J4.2 (COM), K3.11
CH3_NC: J4.3 (NC), K3.12
CH3_NO: J4.1 (NO), K3.14
CH4_COM: J5.2 (COM), K4.11
CH4_NC: J5.3 (NC), K4.12
CH4_NO: J5.1 (NO), K4.14
GND: C1.2, C2.2, C3.2, C4.2, C5.2, C6.2, D5.1 (K), D6.1 (K), D7.1 (K), D8.1 (K), D9.1 (K), D10.1 (A1), D11.1 (A1), D12.1 (A1), D13.1 (A1), D14.1 (A1), D15.1 (A1), D16.1 (A1), J1.2, J6.5, J7.4, Q1.2 (S), Q2.2 (S), Q3.2 (S), Q4.2 (S), R5.2, R6.2, R7.2, R8.2, R14.2, R15.2, TP4.1, U1.7 (VSS)
LED1_A: D5.2 (A), R9.2
LED2_A: D6.2 (A), R10.2
LED3_A: D7.2 (A), R11.2
LED4_A: D8.2 (A), R12.2
NRST: C6.1, D12.2 (A2), J6.4, U1.18 (PF2-NRST)
PFET_G: Q5.1 (G), R14.1
PWR_LED_A: D9.2 (A), R13.2
RLY1_C: D1.2 (A), K1.A2, Q1.3 (D), TP9.1
RLY1_CMD: R1.1, R9.1, U1.3 (PA4)
RLY1_G: Q1.1 (G), R1.2, R5.1, TP5.1
RLY2_C: D2.2 (A), K2.A2, Q2.3 (D), TP10.1
RLY2_CMD: R2.1, R10.1, U1.4 (PA5)
RLY2_G: Q2.1 (G), R2.2, R6.1, TP6.1
RLY3_C: D3.2 (A), K3.A2, Q3.3 (D), TP11.1
RLY3_CMD: R3.1, R11.1, U1.5 (PA6)
RLY3_G: Q3.1 (G), R3.2, R7.1, TP7.1
RLY4_C: D4.2 (A), K4.A2, Q4.3 (D), TP12.1
RLY4_CMD: R4.1, R12.1, U1.6 (PA7)
RLY4_G: Q4.1 (G), R4.2, R8.1, TP8.1
SWCLK: D14.2 (A2), J6.3, U1.11 (PA14-SWC)
SWDIO: D13.2 (A2), J6.2, U1.10 (PA13-SWD)
UART_RX: D16.2 (A2), J7.3, U1.2 (PA3)
UART_TX: D15.2 (A2), J7.2, U1.1 (PA2)
V5IN: D10.2 (A2), J1.1, Q5.3 (D), TP1.1
VCOIL: C1.1, C2.1, D1.1 (K), D2.1 (K), D3.1 (K), D4.1 (K), K1.A1, K2.A1, K3.A1, K4.A1, Q5.2 (S), R13.1, R16.1, TP2.1

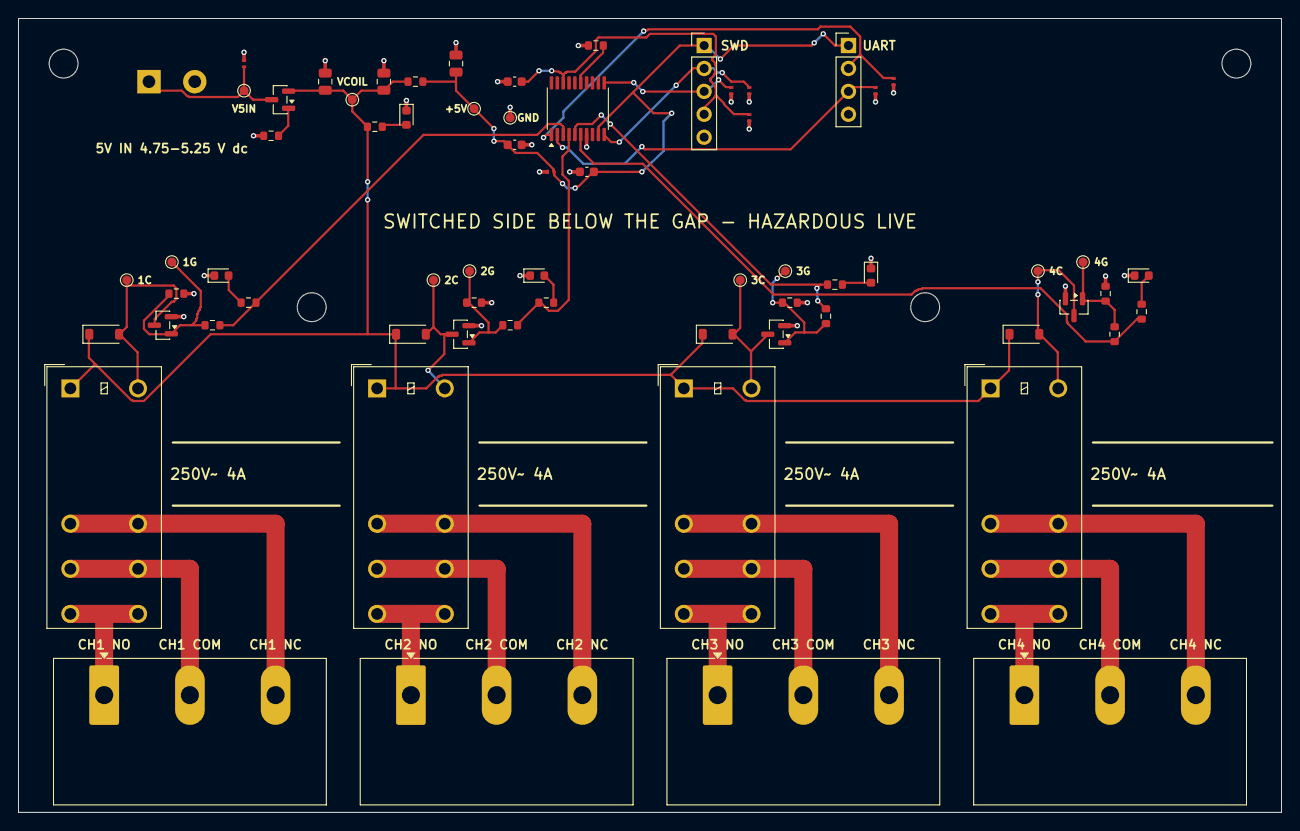
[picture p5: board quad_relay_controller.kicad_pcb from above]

Board: 2 copper layers, 140.0 x 88.0 mm, 71 parts (0 on the bottom side), 40 nets.

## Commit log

2026-08-30 Seed benchmark board 03/32 from its supplied brief
    PCBA_QuadRelayController is one of thirty-two boards in the PCBA_AutoDesignAndTest
    benchmark. This commit establishes the repository and nothing else:
    the board is not designed, and its absence is the intended state.
    BRIEF.md is the supplied brief, preserved byte for byte and
    authoritative. board/requirements.json splits it into fixed_requirements
    -- each carrying the verbatim brief text that substantiates it, bound to
    the SHA-256 of the brief's bytes -- and open_decisions, which are the
    design agent's to make and to record as choices. Promoting a decision
    into a requirement is the failure the split exists to prevent.
    docs/architecture.md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
2026-08-30 Stop the scaffold claiming a check it does not perform
    An external review of the pushed benchmark found this repository asserting
    three things about itself that were not true as shipped.
    board/manifest.template.json said running the validator against it "will
    fail on the missing source". It does not: `run.py validate
    board/manifest.template.json` exits 0 and prints ACCEPTED, with all 36 gates
    NOT_APPLICABLE and no gate reading sources.pcb, so the absent board file is
    never noticed. The template now says exactly that, under verdict_warning,
    and docs/status.md and CLAUDE.md carry the same warning where a reader and
    an agent will actually meet it. The toolkit is behaving as designed - a gate
    w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
2026-08-30 Remove the claim-audit skill, and the instructions that called it
    Requested. .claude/skills/claim-audit/ is deleted, and with it every
    reference: CLAUDE.md's publishing discipline no longer names it, and the
    README layout table no longer advertises it.
    accountability-review kept calling it at step 3, which would have left the
    surviving skill invoking one that is not in the clone - the same
    dangling-instruction defect that put these skills in the repository in the
    first place. That step now states the claim-binding work directly: scan the
    drafts for claim-bearing words, and bind each to an artifact recomputed on
    the spot rather than to the process that produced it. The discipline is
    unchange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
2026-08-30 Finish removing claim-audit: the last prose reference to it
    accountability-review still explained itself with "that is why the claim
    audit runs first". Nothing runs first any more - the claim binding is step 3
    of this skill, and it runs before the review package is assembled, not
    before the review. The sentence now says that.
    Removing a skill is not done when its file is gone. It is done when nothing
    left in the repository tells a reader to go and find it.
2026-08-30 Review against this repository's own invariants, not another board's
    /accountability-review assembled its review package with a hardcoded list
    of "standing invariants", and that list belonged to a different project and
    an abandoned workflow: "never modify the authoritative Board A PCB" names a
    board that does not exist here, and "never touch main" and "no PRs"
    describe a process the opposite of this one -- every repository in this
    benchmark is developed on main and pushed directly.
    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
2026-08-30 Delete generated prose; keep the seed brief and machine-consumed config
    The seed pack already contained the human-authored specification for this
    board. Everything this repository added on top was a reinterpretation of it:
    a README and CLAUDE.md narrating the brief, an architecture worksheet of
    English questions, status and sources documents, a prose requirements
    document, and requirements.json - which restated the brief as English
    requirement strings and copied 20-odd verbatim quotations back out of a file
    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
2026-09-02 Design the quad relay controller: schematic, placement, routing and evidence
    Four channels of 250 VAC / 4 A relay, driven from a 5 V logic input, with
    the switched side separated from the logic side by 9 mm of bare laminate.
    The separation is the design. Its figure is derived in design/clearance.py
    from IEC 60664-1 tables F.1, F.2 and F.4 - as reproduced in the two frozen
    TI papers - at the declared 250 V rms working voltage, and it comes out at
    8.0 mm reinforced and 2.8 mm functional. Both are enforced by custom KiCad
    design rules written from that same derivation, so the rule file and the
    documentation cannot disagree; the layout keeps 9.25 mm and 3.00 mm. The
    figure also matches the rela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
    [bom.csv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]
2026-09-02 Rebuild the fabrication outputs against the committed source closure
    The previous commit carried artifacts generated before the manifest named
    generated/requirements.json as required evidence, so the recorded closure
    described a design one edit older than the one in the tree.
    [quad_relay_controller-B_Cu.gbr, quad_relay_controller-B_Mask.gbr, quad_relay_controller-B_Silkscreen.gbr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]
2026-09-02 Check the insulation derivation against the relay's own certification
    The G2RL datasheet carries a certified insulation classification that was
    not extracted the first time: material group IIIa, coil-to-contact
    insulation type reinforced, rated insulation voltage 250 V, pollution
    degree 3, overvoltage category III.
    Two of those turn assumptions into checks. The derivation reads the group
    III column of IEC 60664-1 table F.4 and the relay is certified IIIa, which
    is inside it - so rules.py now compares the two rather than the board
    merely asserting a group. And the relay is certified reinforced at exactly
    the 250 V this board is marked for, which is the classification the
    boundary was designe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
    [quad_relay_controller-B_Cu.gbr, quad_relay_controller-B_Mask.gbr, quad_relay_controller-B_Silkscreen.gbr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]
2026-09-02 Record what kind of statement each requirement is
    Every requirement was recorded as though the brief had stated it. It had
    not: some are derived from a datasheet limit or an insulation standard,
    and some are thresholds this design simply chose - a flyback loop area
    target, a tenth-of-input budget for the reverse-polarity drop, a 20 degC
    conductor rise. Presenting a choice as a user requirement hides which of
    four different things went wrong when a board fails.
    design/requirements.py registers all 35 requirements with their kind,
    what they were derived from, why, the alternatives the chosen ones were
    chosen over, and the verification methods that establish them. It also
    carries the nine stat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
    [quad_relay_controller-B_Cu.gbr, quad_relay_controller-B_Mask.gbr, quad_relay_controller-B_Silkscreen.gbr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]
2026-09-02 Simulate the coil turn-off clamp against a bounded diode model
    The drain stress at turn-off was established analytically, taking the
    diode's forward drop at the highest current the datasheet characterises
    because no model existed to evaluate it at the current the coil actually
    carries.
    design/models.py registers one now, derived from the frozen datasheet
    rather than from a vendor library. The datasheet gives maximum forward
    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
    [quad_relay_controller-B_Cu.gbr, quad_relay_controller-B_Mask.gbr, quad_relay_controller-B_Silkscreen.gbr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]
2026-09-02 Declare the command path as a path, not as two nets
    A KiCad net stops at a series component, and the driver gate is on the
    far side of one: the MCU pin drives RLYn_CMD, the gate sits on RLYn_G,
    and measuring either alone measures a fragment. The same pin also feeds
    the indicator through a second resistor, which is the branch the per-pin
    current claim assumes exists.
    Eight electrical paths are declared - four command, four indicator -
    each as copper, a component traversal, copper. TIMING.PATH_INTEGRITY now
    resolves all eight end to end against the board's actual copper and
    checks that each crosses the series part it declares; a path that
    started on the wrong side of its resistor would fail r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
    [quad_relay_controller-B_Cu.gbr, quad_relay_controller-B_Mask.gbr, quad_relay_controller-B_Silkscreen.gbr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]
2026-09-02 Refresh the frozen fabrication inputs against the current catalog
    The toolkit's JLCPCB catalog gained a dielectric constant stated for a
    two-layer laminate, moving its content digest. This board's frozen copper
    records still claimed the old one, so extract.verify_approved_parameter
    refused them - correctly: a record whose digest no longer matches is a
    claim about a catalog that is no longer there.
    Every engineering value is unchanged; only the digest moved. Selection is
    regenerated alongside, and now records that no two-layer construction is
    published while one can be composed from stated values.
    [quad_relay_controller-B_Cu.gbr, quad_relay_controller-B_Mask.gbr, quad_relay_controller-B_Silkscreen.gbr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]
2026-09-02 Estimate the board's heat at a declared 40 degC maximum ambient
    The brief conditions its dissipation requirement on "maximum ambient" and
    states no figure, so nothing was derating anything. The board declares
    40 degC now: below the resistors' 70 degC derating knee, and 45 degC
    below the lowest rated ambient on the board, which is the relay's.
    That immediately caught a defect. The drivers were judged against the
    AO3400A's 0.9 W figure, which the datasheet quotes against its TEN-SECOND
    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
    [quad_relay_controller-B_Cu.gbr, quad_relay_controller-B_Mask.gbr, quad_relay_controller-B_Silkscreen.gbr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]
2026-09-02 Measure the routing angles instead of declaring a style
    ROUTE.ANGLE_STYLE was left undeclared because the router emits corners
    off the 45-degree grid. That was honest but it left the property absent
    rather than answered, and "the board declares no style" and "nobody
    looked" read identically in an undeclared gate.
    route.angle_census reads the corners off the board: 270 of them, 252
    turning by a multiple of 45 degrees. Of the 18 that do not, 17 have an
    arm shorter than 0.15 mm and are the stubs the router lays to reach a
    pad centre. Exactly one is a routing decision off the grid: a 46.2
    degree turn on +5V on the back layer with a 3.3 mm arm.
    The decision to declare no style is now recorded w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
    [quad_relay_controller-B_Cu.gbr, quad_relay_controller-B_Mask.gbr, quad_relay_controller-B_Silkscreen.gbr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]
2026-09-02 Derive every placement angle's library-zero correction from evidence
    A placement angle is not a property of the board alone. Where the
    assembly library holds a part at a different zero orientation from the
    footprint, every instance is fitted turned by the difference, and until
    now this board shipped its raw KiCad angles - which is the same as
    asserting every correction is zero without having looked.
    Six of this board's nineteen part numbers need a correction. The SOT-23
    drivers and the input FET need 180 degrees, the TSSOP-20 MCU and both
    pin headers and the relay need 270. The one that would have hurt is the
    LED: 180 degrees, while the SOD-123 diode beside it needs none. Both are
    two-pad p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
    [cpl.csv, quad_relay_controller-B_Cu.gbr, quad_relay_controller-B_Mask.gbr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]
2026-09-03 Ask the toolkit for what this board had to build itself
    Eleven requests, each written board-agnostically and grounded in
    something that happened here, ordered by what they would cost the next
    board.
    The largest is a manifest schema: every declaration made for this board -
    the model registry, the electrical paths, the orientation registry, the
    fab format - was reverse-engineered from gate source and toolkit tests,
    and one of them cost a full validation cycle to discover that an
    interface wraps its paths in a "routes" object.
    The one that would have shipped a wrong board rather than costing time
    is that a build with an orientation registry and no fab_format applies
    none of it, reports succes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
2026-09-03 Rebind the release to the phase 0 toolkit
    The toolkit now validates every manifest against its published schema
    and refuses vocabulary it does not implement, so the board-local gate
    list moves under the x_ extension prefix; gate-class selection
    (--only=design) supersedes it. Regenerated and revalidated against
    toolkit f4d3904: 26 gates pass, 10 report NOT_APPLICABLE, and
    the fabrication record now carries the source-closure member map, so
    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
    [quad_relay_controller-B_Cu.gbr, quad_relay_controller-B_Mask.gbr, quad_relay_controller-B_Silkscreen.gbr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]
2026-09-03 Retire the hand-written routing acceptance list
    The toolkit's design gate class replaces it: candidate acceptance now
    selects --only=design, expanded by the toolkit, so the set cannot rot
    as gates are added. The list leaves the manifest and the routing script that read it, and the
    release is regenerated under toolkit b441685, which also closes the
    review findings on the phase 0 seams: 26 gates pass, 10 report
    NOT_APPLICABLE.
    [quad_relay_controller-B_Cu.gbr, quad_relay_controller-B_Mask.gbr, quad_relay_controller-B_Silkscreen.gbr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]
2026-09-03 Close the adversarial findings that reached this board
    The unread keys the manifest carried are gone: tolerance_seconds is
    deleted, contact_semantics becomes the note annotation it always was,
    and the schema now refuses both by name. The routing acceptance
    selection regains ROUTE.PROVENANCE - the loop writes the record before
    judging, so record-board agreement is judged per candidate as it was
    under the hand-written list, and the acceptance tests now assert the floor of gates the loop depends on as well as the artifact-gate exclusions. Regenerated and revalidated under
    toolkit a0f53eb: 26 gates pass, 10 report NOT_APPLICABLE.
    [quad_relay_controller-B_Cu.gbr, quad_relay_controller-B_Mask.gbr, quad_relay_controller-B_Silkscreen.gbr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]
2026-09-03 Rebind the release to toolkit 0c051f2
    The toolkit keeps its CLI alive with no display and closes the third
    review round's findings; nothing in this board's own sources moved.
    26 gates pass, 10 report NOT_APPLICABLE.
    [quad_relay_controller-B_Cu.gbr, quad_relay_controller-B_Mask.gbr, quad_relay_controller-B_Silkscreen.gbr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]
2026-09-03 Rebind the release to toolkit 7f51066
    The panel-fix round widened the source closure to every staged design
    input and hardened the verdict binding, so the fabrication outputs and
    the recorded verdict are regenerated under the new toolkit. The
    transient .pcbqa-hold-* lock file is ignored.
    The orientation registry's review provenance the toolkit never reads
    (review basis, margins, pairing, references) moves under x_-prefixed
    keys, regenerated through this board's own emitter; the toolkit's
    schema now admits exactly the fields its registry reader consumes.
    [quad_relay_controller-B_Cu.gbr, quad_relay_controller-B_Mask.gbr, quad_relay_controller-B_Silkscreen.gbr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]
